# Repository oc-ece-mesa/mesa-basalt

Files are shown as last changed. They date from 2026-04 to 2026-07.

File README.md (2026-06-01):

# MESA Basalt

<div>
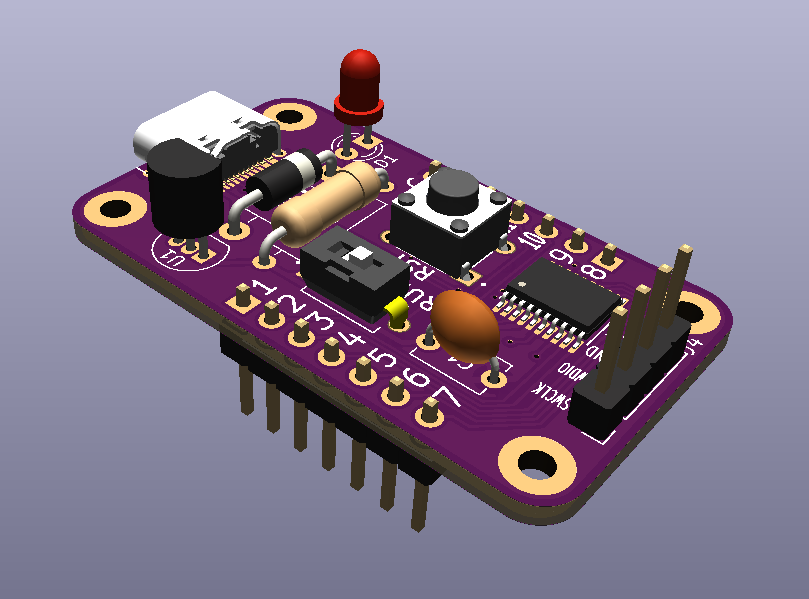
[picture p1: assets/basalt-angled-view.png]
    
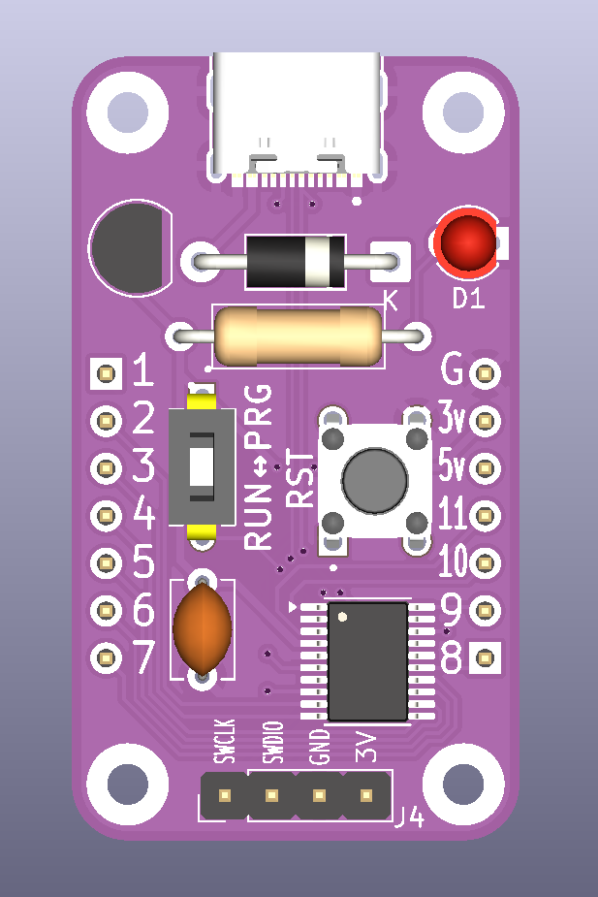
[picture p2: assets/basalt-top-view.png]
    
</div>

Basalt is a cost effective and easy to assemble (mostly through-hole components) devboard based on the STM32C071 microcontroller.

## Docs

1. [Parts List](docs/parts-list.md)
2. [Assembly & Setup](docs/assembly-and-setup.md)
3. [Dev Env Setup](docs/dev-env-setup.md)

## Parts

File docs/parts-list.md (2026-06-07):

# Basalt Parts List

<table>
    <thead>
        <tr>
            <th>QTY</th>
            <th>COST/EA</th>
            <th>DESC</th>
            <th>MFG</th>
            <th>P/N</th>
        </tr>
    </thead>
    <tbody>
        <tr>
            <td>1</td>
            <td>$2.60</td>
            <td>Basalt PCB</td>
            <td>MESA</td>
            <td>mesa-basalt-reva</td>
        </tr>
        <tr>
            <td>1</td>
            <td>$1.10</td>
            <td>Microcontroller</td>
            <td>STM</td>
            <td>STM32C071F8P6</td>
        </tr>
        <tr>
            <td>1</td>
            <td>$0.08</td>
            <td>3.3V Regulator</td>
            <td>Diotec</td>
            <td>DI78L3.3ZAB</td>
        </tr>
        <tr>
            <td>1</td>
            <td>$0.14</td>
            <td>100nF Capacitor</td>
            <td>TDK</td>
            <td>FG28X7R1H104KNT00</td>
        </tr>
        <tr>
            <td>1</td>
            <td>$0.18</td>
            <td>LED</td>
            <td>Würth Elektronik</td>
            <td>15103xxxxxxxx</td>
        </tr>
        <tr>
            <td>1</td>
            <td>$0.03</td>
            <td>2kΩ Resistor</td>
            <td>Stackpole</td>
            <td>CF12JT2K00</td>
        </tr>
        <tr>
            <td>2</td>
            <td>$0.08</td>
            <td>Pin Header</td>
            <td>Stackpole</td>
            <td>CF12JT2K00</td>
        </tr>
        <tr>
            <td>1</td>
            <td>$0.41</td>
            <td>USB Connector</td>
            <td>GCT</td>
            <td>USB4215-03-A</td>
        </tr>
        <tr>
            <td>1</td>
            <td>$0.09</td>
            <td>Pushbutton</td>
            <td>Same Sky</td>
            <td>TS02-66-50-BK-260-LCR-D</td>
        </tr>
        <tr>
            <td>1</td>
            <td>$0.46</td>
            <td>Switch</td>
            <td>Same Sky</td>
            <td>DS04-254-1L-01BK</td>
        </tr>
        <tr>
            <td>1</td>
            <td>$0.16</td>
            <td>Schottky Diode</td>
            <td>TSMC</td>
            <td>1N5817</td>
        </tr>
        <tr>
            <td>1</td>
            <td>$0.12</td>
            <td>Right Angle Pin Header</td>
            <td>Adam Tech</td>
            <td>PH1RB-04-UA </td>
        </tr>
    </tbody>
</table>

**Total Cost**: $5.45

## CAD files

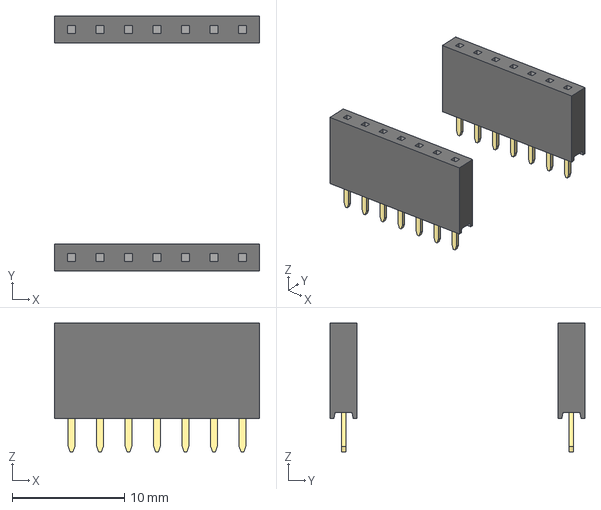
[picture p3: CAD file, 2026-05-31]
kicad-part/MESA_Basalt_RevA_Socket_Headers.step
18.3 x 22.7 x 11.5 mm

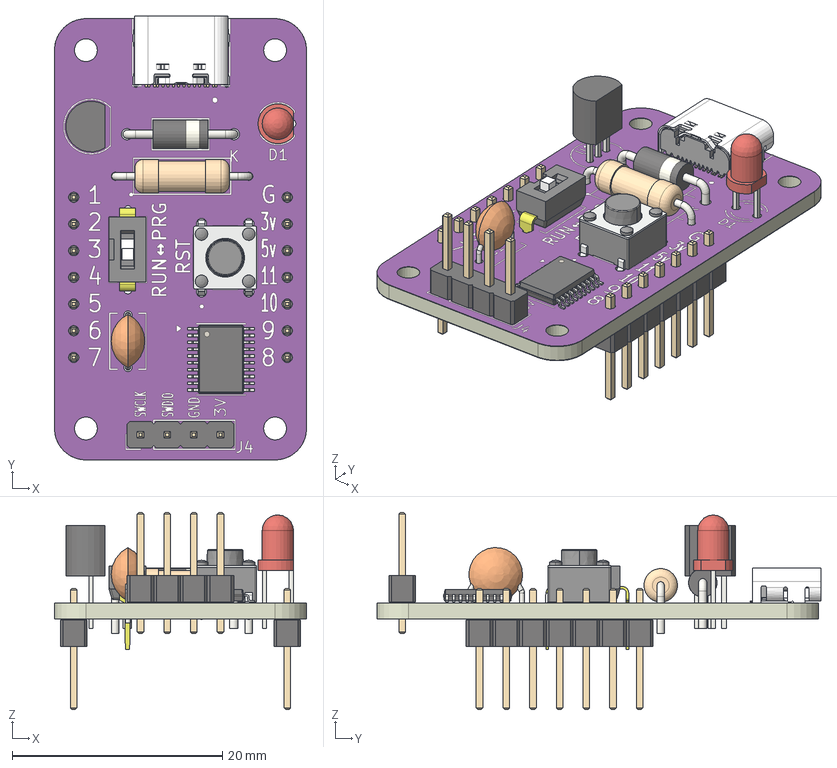
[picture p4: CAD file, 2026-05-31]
kicad-part/MESA_Basalt_RevA.step
24.0 x 42.3 x 18.8 mm
TSSOP-20_4.4x6.5mm_P0.65mm
PinHeader_1x04_P254mm_Vertical
HSG_ASM_1
TO-92_Inline_Narrow
D_DO-41_SOD81_P10.16mm_Horizontal
LED_D3.0mm
C_Disc_D51mm_W32mm_P500mm
CUI_DEVICES_DS04-254-1L-01BK
CUI_DEVICES_TS02-66-50-BK-260-SCR-D
R_Axial_DIN0309_L90mm_D32mm_P1270mm_Horizontal
PinHeader_1x07_P254mm_Vertical x 2
basalt-pcb_silkscreen x 2
basalt-pcb_soldermask x 2
basalt-pcb_PCB

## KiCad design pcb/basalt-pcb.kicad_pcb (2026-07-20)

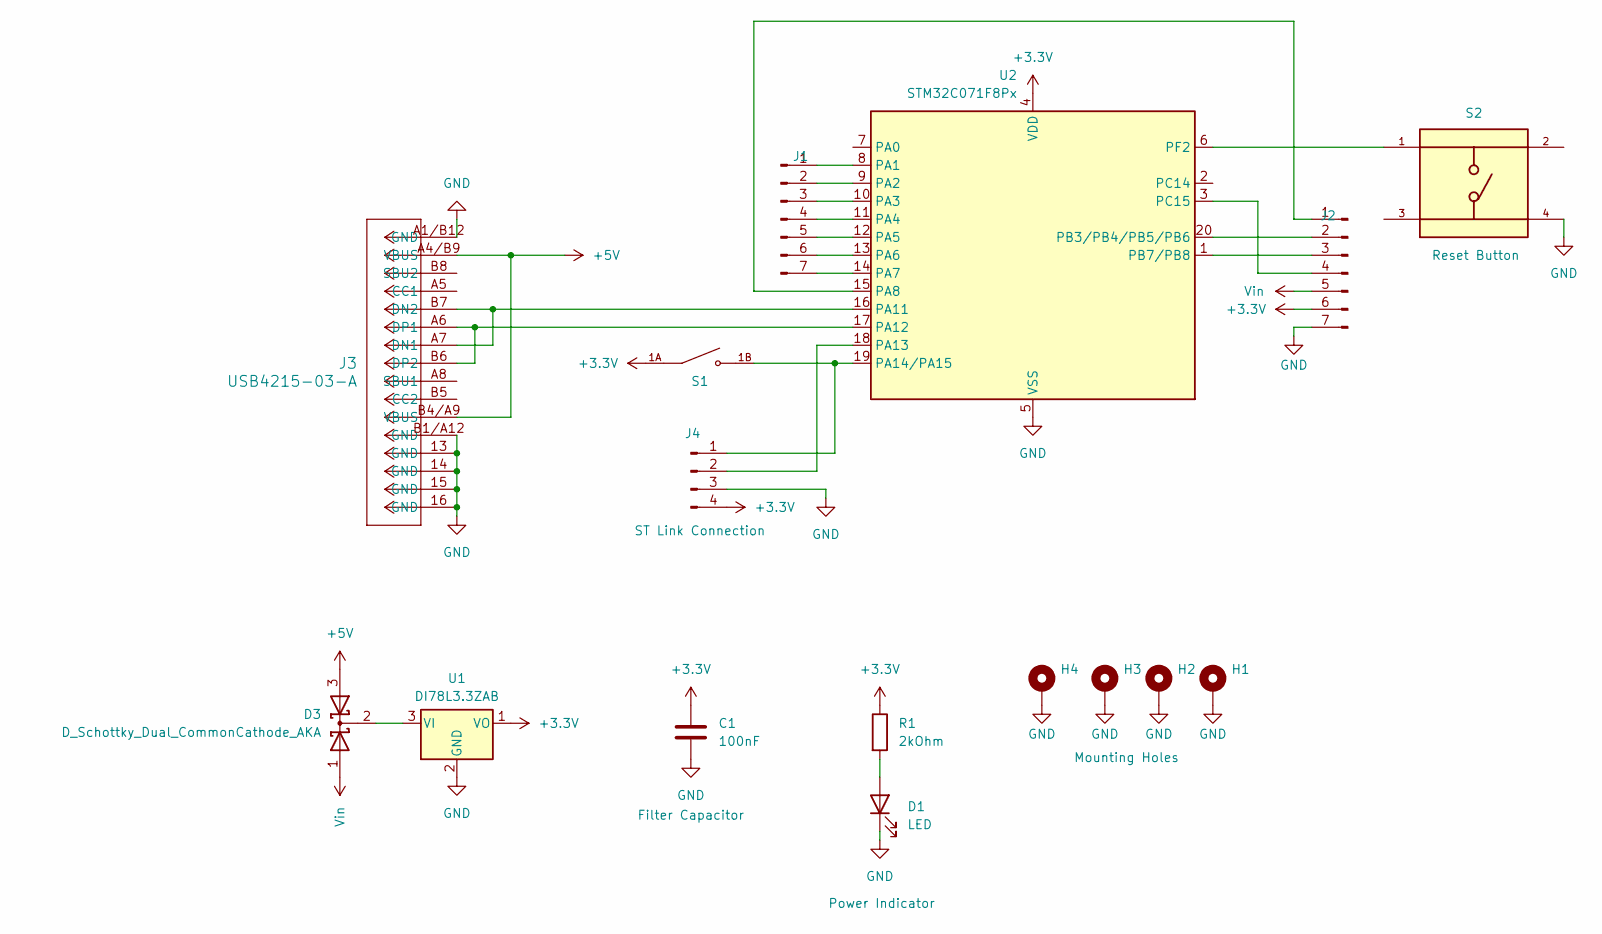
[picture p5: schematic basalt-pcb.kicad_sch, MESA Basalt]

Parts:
C1: 100nF; C_Disc_D5.1mm_W3.2mm_P5.00mm
D1: LED; LED_D3.0mm
D3: D_Schottky_Dual_CommonCathode_AKA; TO-220-3_Vertical
H1, H2, H3, H4: MountingHole_Pad; MountingHole_2.2mm_M2_Pad
J1, J2: Conn_01x07_Pin; PinHeader_1x07_P2.54mm_Vertical
J3: USB4215-03-A; CONN_8p94X6p5X3p16_12L_GCC
J4: Conn_01x04_Pin; PinHeader_1x04_P2.54mm_Vertical
R1: 2kOhm; R_Axial_DIN0309_L9.0mm_D3.2mm_P12.70mm_Horizontal
S1: DS04-254-1L-01BK; SW_DS04-254-1L-01BK; PARTREV V0.0
S2: TS02-66-50-BK-260-SCR-D; SW_TS02-66-50-BK-260-SCR-D; PARTREV 1.0
U1: DI78L3.3ZAB; TO-92_Inline
U2: STM32C071F8Px; TSSOP-20_4.4x6.5mm_P0.65mm

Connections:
+3.3V: C1.1, J2.6, J4.4, R1.1, S1.1A, U1.1 (VO), U2.4 (VDD)
+5V: D3.3 (A), J3.A4/B9 (VBUS), J3.B4/A9 (VBUS)
GND: C1.2, D1.1 (K), H1.1 (1_1), H2.1 (1_1), H3.1 (1_1), H4.1 (1_1), J2.7, J3.13 (GND), J3.14 (GND), J3.15 (GND), J3.16 (GND), J3.A1/B12 (GND), J3.B1/A12 (GND), J4.3, S2.4, U1.2 (GND), U2.5 (VSS)
unnamed: D1.2 (A), R1.2
unnamed: D3.2 (K), U1.3 (VI)
unnamed: J1.1, U2.8 (PA1)
unnamed: J1.2, U2.9 (PA2)
unnamed: J1.3, U2.10 (PA3)
unnamed: J1.4, U2.11 (PA4)
unnamed: J1.5, U2.12 (PA5)
unnamed: J1.6, U2.13 (PA6)
unnamed: J1.7, U2.14 (PA7)
unnamed: J2.1, U2.15 (PA8)
unnamed: J2.2, U2.20 (PB3/PB4/PB5/PB6)
unnamed: J2.3, U2.1 (PB7/PB8)
unnamed: J2.4, U2.3 (PC15)
unnamed: J3.A7 (DN1), J3.B7 (DN2), U2.16 (PA11)
unnamed: J3.A6 (DP1), J3.B6 (DP2), U2.17 (PA12)
unnamed: J4.1, S1.1B, U2.19 (PA14/PA15)
unnamed: J4.2, U2.18 (PA13)
unnamed: S2.1, U2.6 (PF2)
Vin: D3.1 (A), J2.5

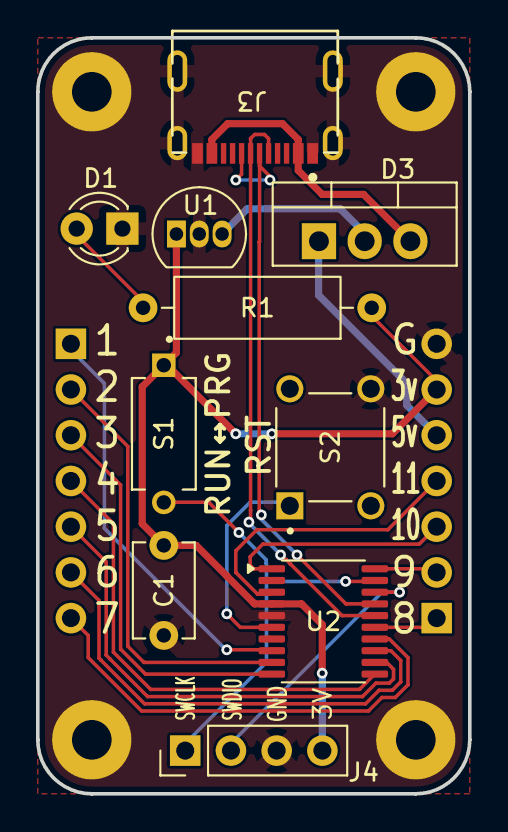
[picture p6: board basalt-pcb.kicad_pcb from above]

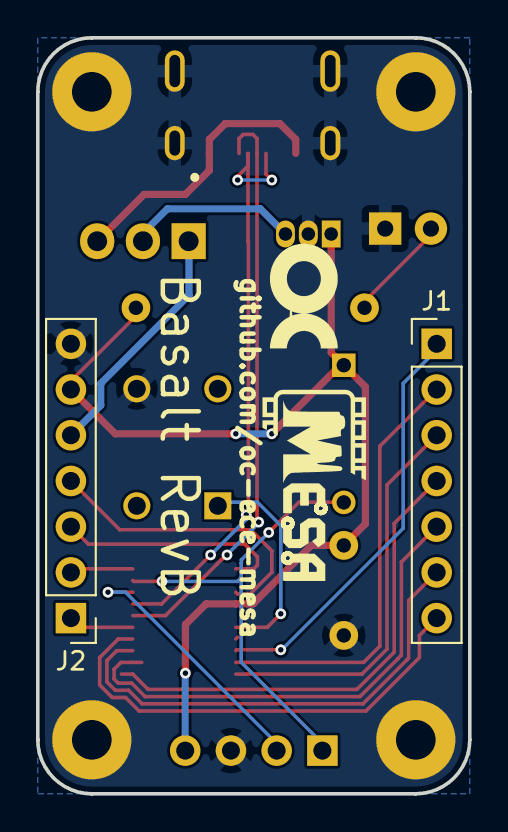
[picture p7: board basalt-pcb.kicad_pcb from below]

Board: 2 copper layers, 24.0 x 42.0 mm, 16 parts (2 on the bottom side), 22 nets.

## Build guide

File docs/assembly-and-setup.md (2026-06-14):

# **Assembly**

1. Solder the SMD parts (USB C connector, and MCU) first, using solder paste

   ***NOTE**: You can use a soldering iron, but it is tricky, make sure to use a fine tip*
   
   ***NOTE**: It is recommended to not solder all of the USB C connector case fins at this step, just lightly solder one of them, that way the connector can be removed easier if you need to resolder it after testing*
   
2. Verify there are no shorts with a multimeter (particularly check between the GND and 5V pins)
3. Solder the 3.3V regulator and diode
4. You now have the minimal required parts for the USB to work, plug the board into a computer to test if it shows up as a USB device. If it does not, you have a short or bad connection somewhere.
5. Solder all remaining components

   ***NOTE**: For the program mode switch, the side that says “ON” points towards the silkscreen text “PRG”.*
   
   ***NOTE**: For the LED, the flat side points toward the square pad.*

# **Setting Option Bits**

1. Setup your MCUs option bits to allow entering USB bootmode after initial programming
   - Plug your dev board into your computer with a USB-C cable
   - Run STM32CubeProgrammer
   - Select “USB” in the dropdown in the upper right corner

<p align="center">
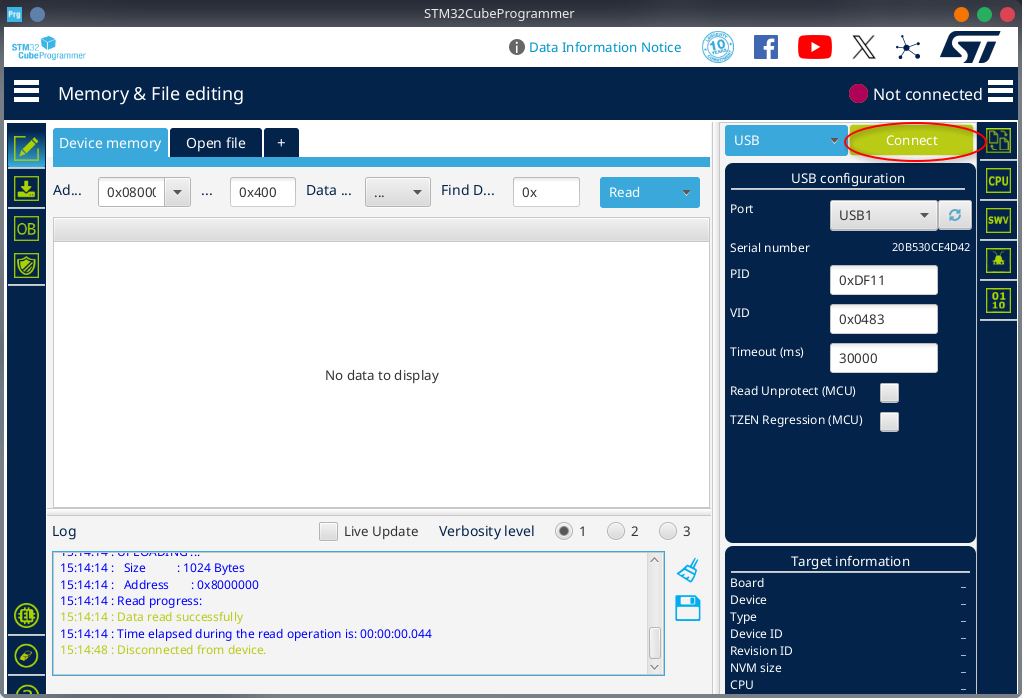
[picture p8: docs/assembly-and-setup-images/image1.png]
    
</p>

2. Click the Port refresh button, the port should auto populate as shown

<p align="center">
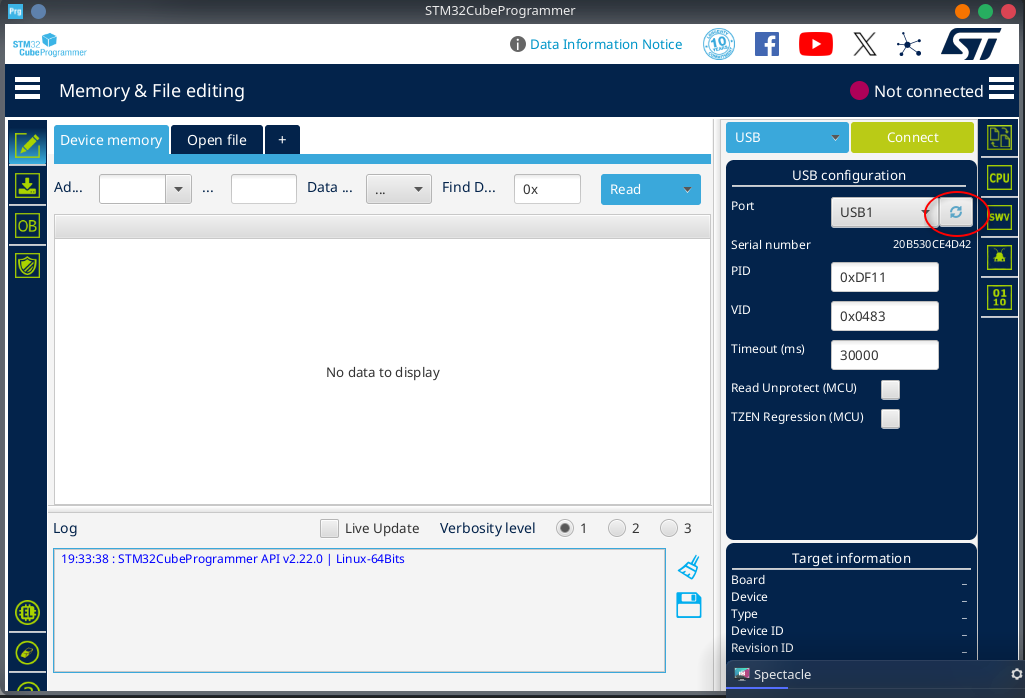
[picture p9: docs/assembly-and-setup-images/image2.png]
    
</p>

3. Click “Connect”

<p align="center">
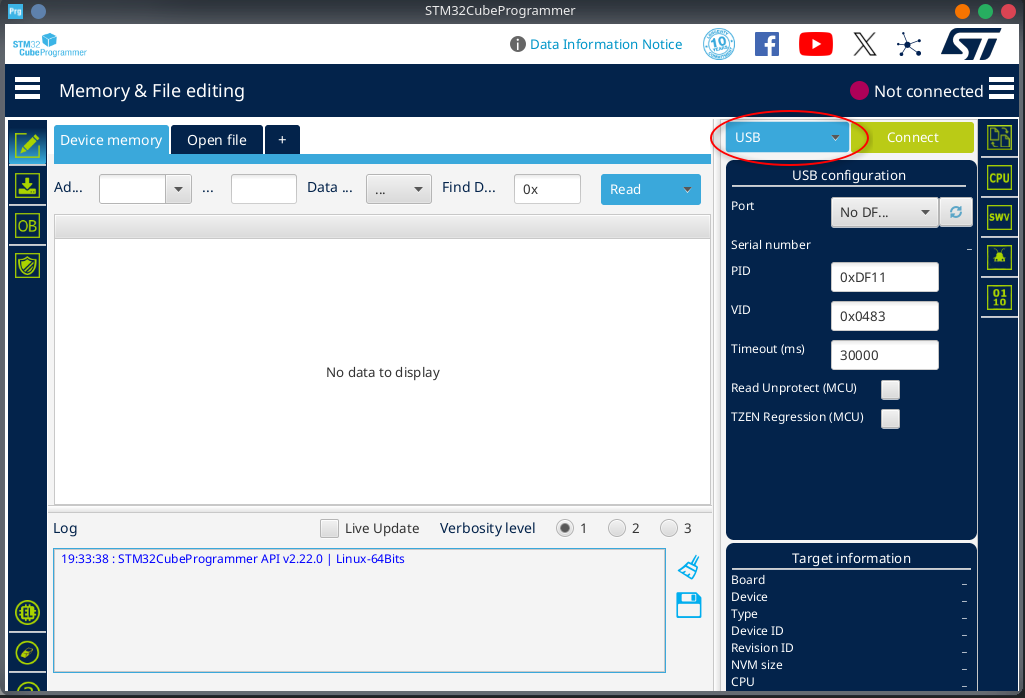
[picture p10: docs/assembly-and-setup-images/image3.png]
    
</p>

You should see the indicator turn green and say “Connected” and the section on the left should populate with binary data, as shown below.

<p align="center">
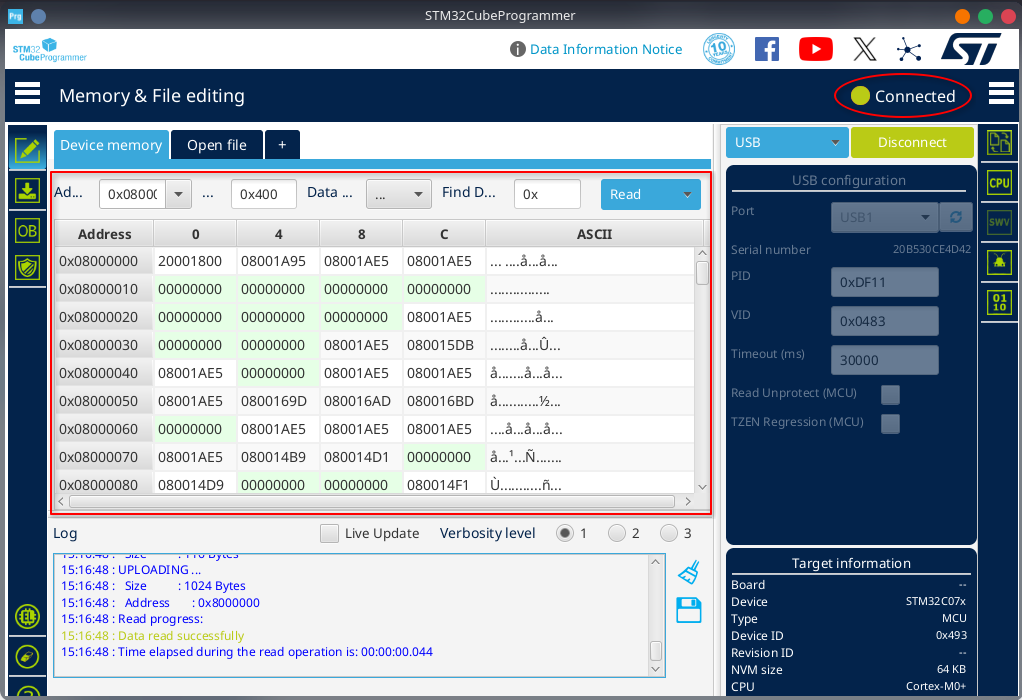
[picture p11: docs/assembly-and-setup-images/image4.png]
    
</p>

4. Click on “OB” on the left-hand toolbar and open the “User Configuration” dropdown

<p align="center">
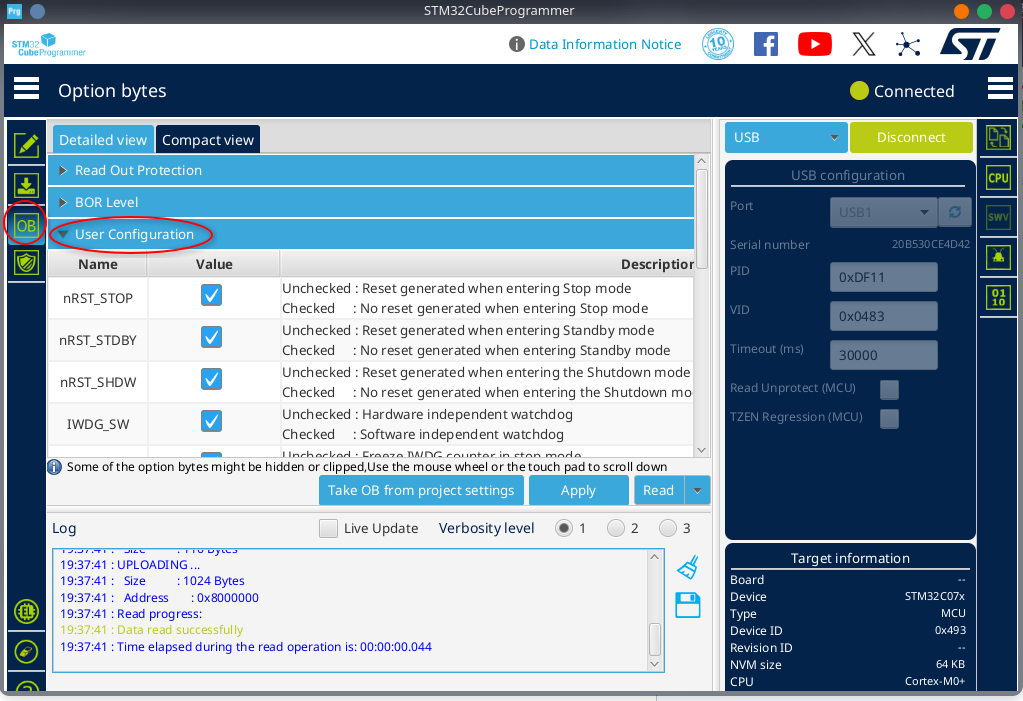
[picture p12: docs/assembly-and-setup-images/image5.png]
    
</p>

5. Scroll down to “nBOOT\_SEL” and uncheck it; then click “Apply”.

<p align="center">
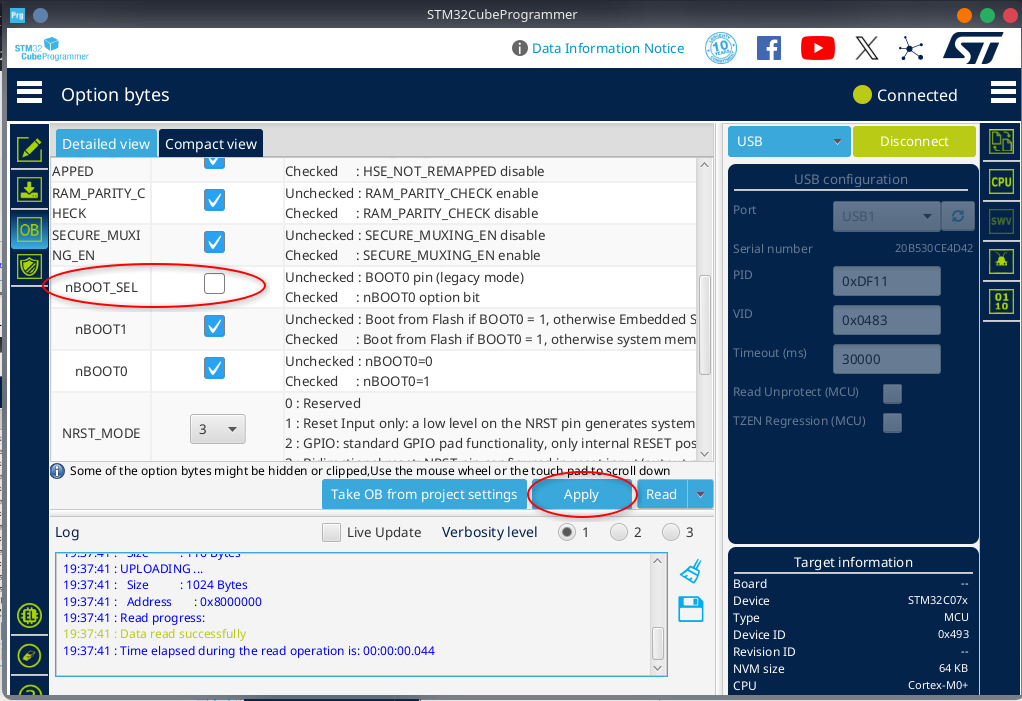
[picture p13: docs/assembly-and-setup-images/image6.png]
    
</p>

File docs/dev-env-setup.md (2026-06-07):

# Basalt Dev Env Setup

## Setup Development Environment

1. Install Arduino IDE

	**Note**: *Arduino IDE may be in your app store / software center, check there first. Otherwise, follow the steps below*

   - Go to Arduino’s software page [here](https://www.arduino.cc/en/software/)
   - Scroll down to the Arduino IDE box
   - Select your OS from the dropdown and click “DOWNLOAD”

<p align="center">
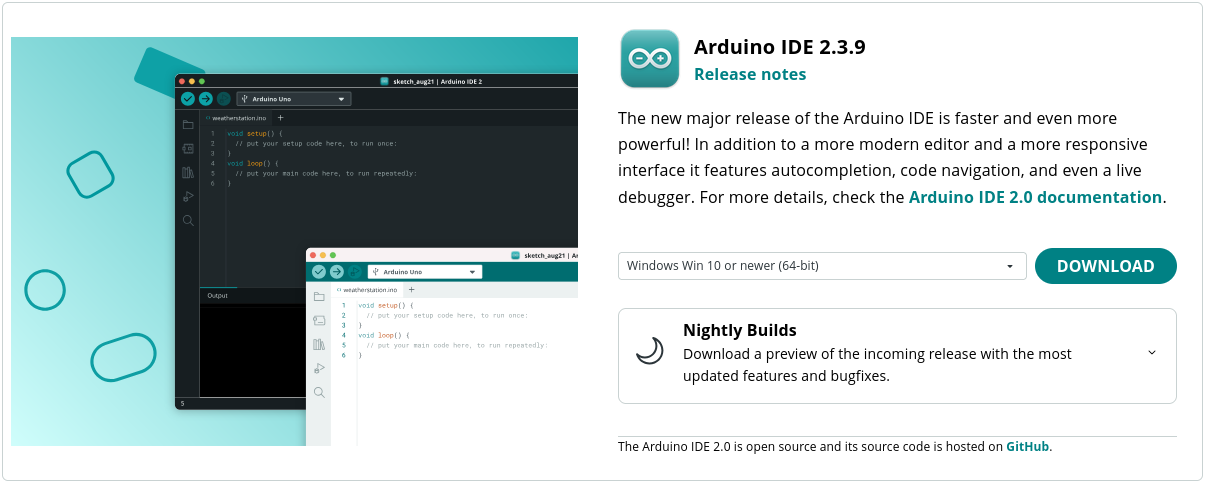
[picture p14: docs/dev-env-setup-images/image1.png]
    
</p>

2. Run the installer
3. Add support for STM32 boards
   - In Arduino IDE, under File / Preferences, add `https://github.com/stm32duino/BoardManagerFiles/raw/main/package\_stmicroelectronics\_index.json` to “Additional boards manager URLs”

<p align="center">
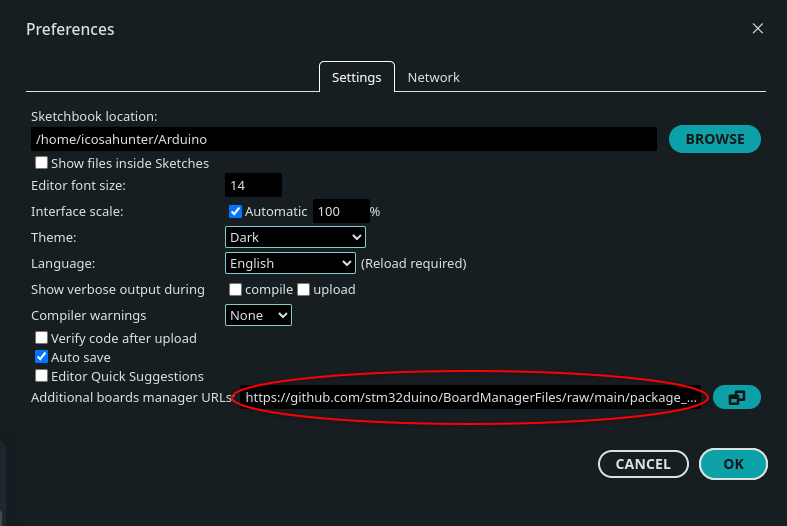
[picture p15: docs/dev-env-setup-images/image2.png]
    
</p>

2. Under Tools / Board / Boards Manager… search for and install “STM32 MCU based boards”

<p align="center">
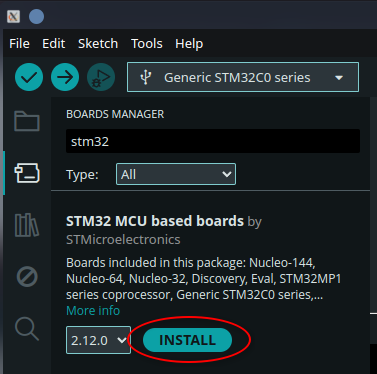
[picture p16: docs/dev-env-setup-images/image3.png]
    
</p>

3. Install STM32CubeProgrammer
   - Download the appropriate installer for your OS from [here](https://www.st.com/en/development-tools/stm32cubeprog.html#st-get-software)  
   - Follow the install instructions for your OS from the software manual [here](https://www.st.com/resource/en/user_manual/um2237-stm32cubeprogrammer-software-description-stmicroelectronics.pdf)

## Setup a New Arduino Sketch

1. Run Arduino IDE
2. Under File click “New Sketch”
3. Hover over the dropdown next to the run button and click “Select other board and port…”

<p align="center">
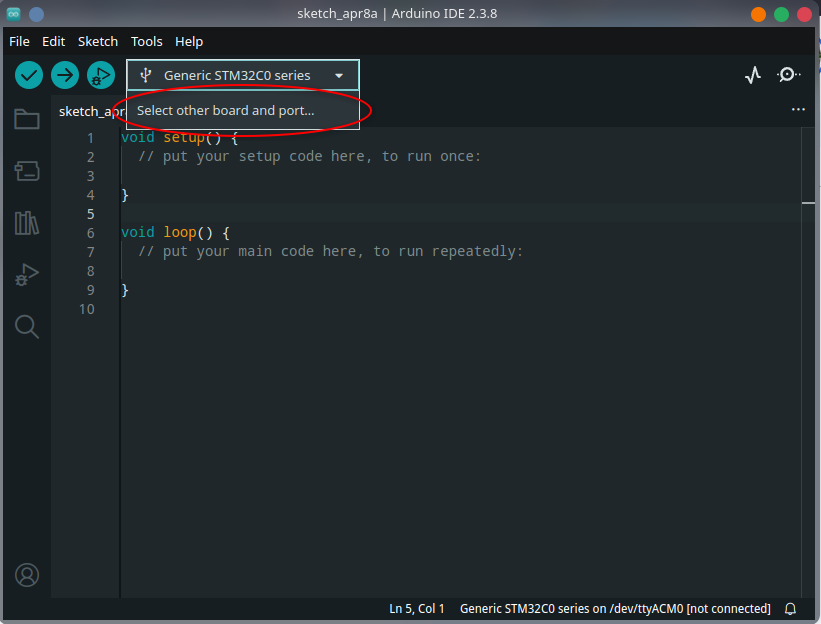
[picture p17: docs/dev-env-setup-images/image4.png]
    
</p>

4. In the pop-up search for and select “Generic STM32C0 series” and then click “OK”.

<p align="center">
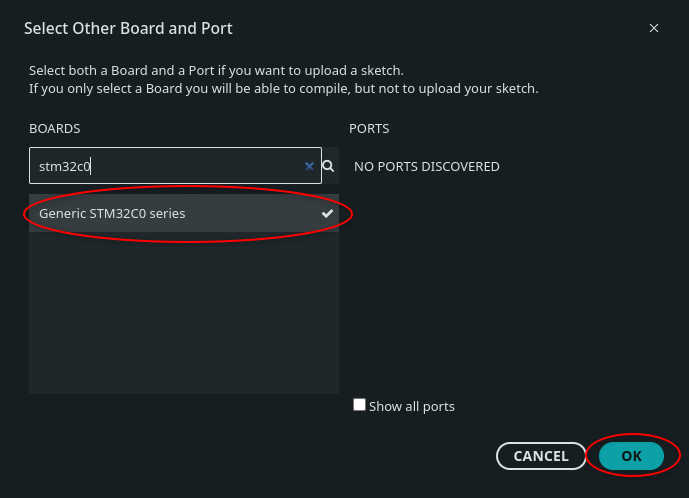
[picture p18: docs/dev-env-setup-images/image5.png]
    
</p>

5. Under Tools / Board part number: Select “Generic C071G8Ux”

<p align="center">
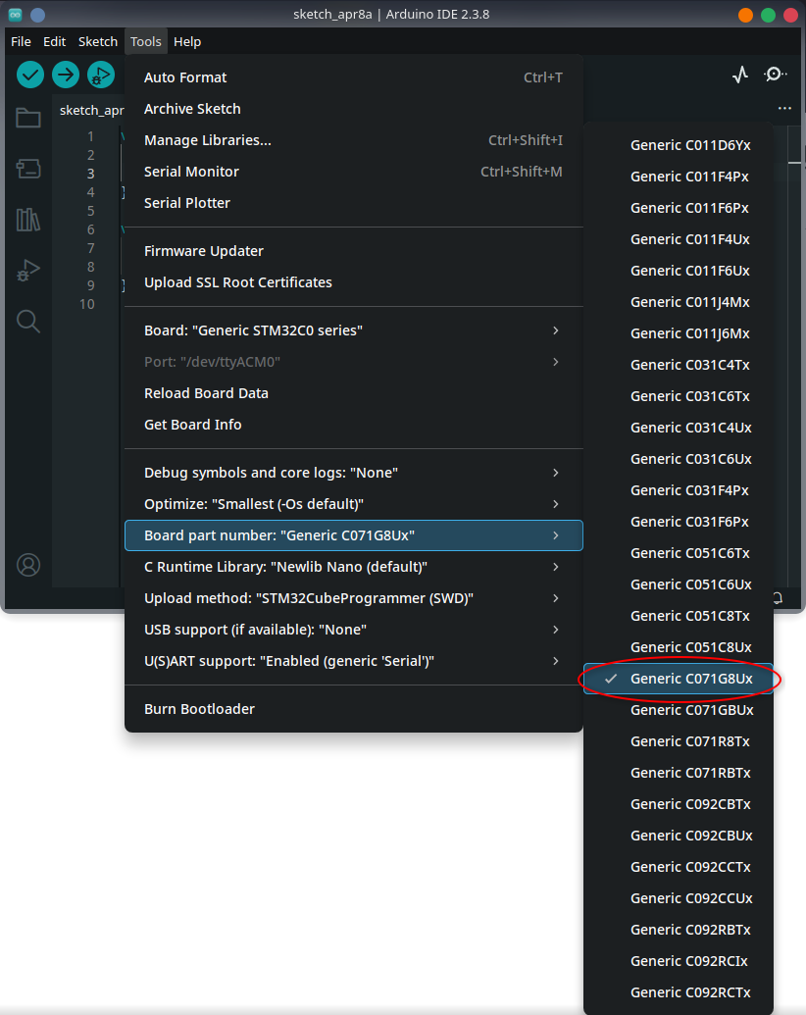
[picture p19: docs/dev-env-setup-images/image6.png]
    
</p>

6. Under Tools / Upload method: Select “STM32CubeProgrammer (DFU)”

<p align="center">
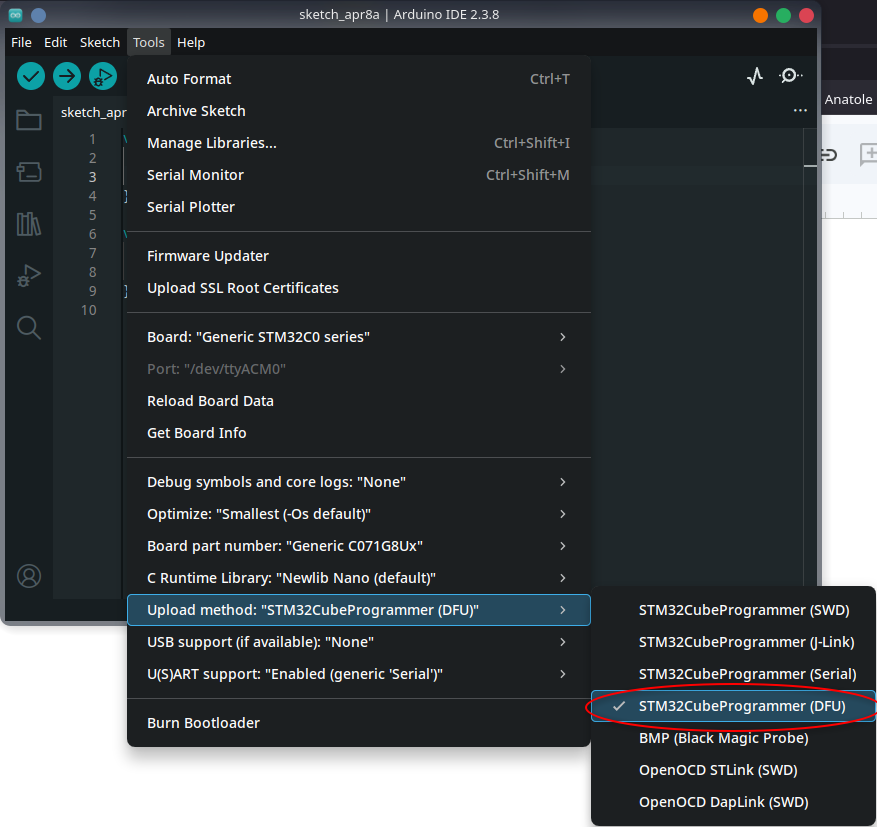
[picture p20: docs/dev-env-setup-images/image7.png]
    
</p>

7. Save your sketch with Ctrl \+ S

## Upload a Sketch to the Board

1. Open the sketch in Arduino IDE
2. Plug your breadboard into your computer with a USB-C cable
3. Set “PRG SW” to closed position and click “RST BTN” on your breadboard

	**Note**: *If PRG SW is closed, the board will boot into USB DFU mode on a reboot/reset, otherwise it will boot into your program, if there is one.*

4. Your computer should get a notification that a USB device named “STMicroelectronics DFU in FS Mode” has been connected.  
5. Click the “Start Debugging” button. After the upload is complete you should see a success message in the output box and get a notification that the USB device has disconnected.

<p align="center">
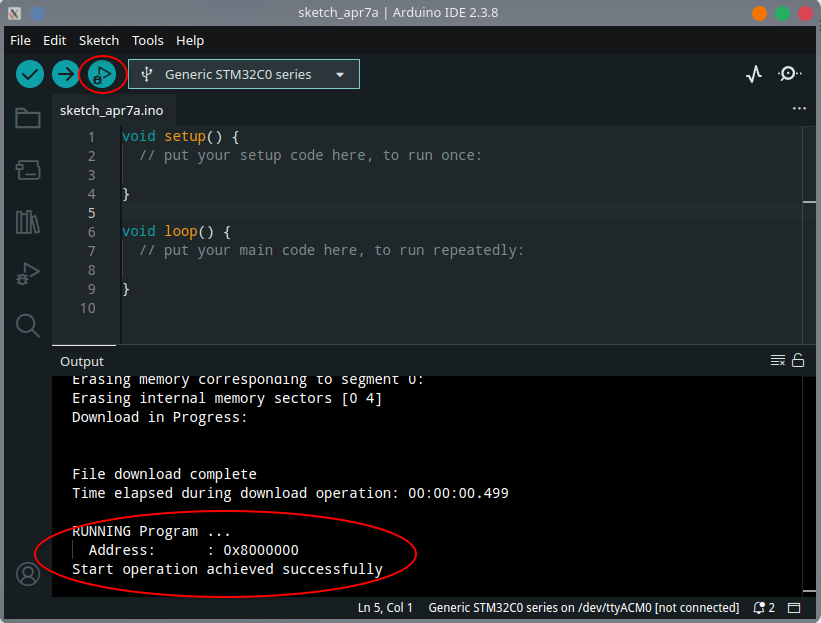
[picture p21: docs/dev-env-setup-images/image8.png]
    
</p>

6. Set “PRG SW” to open position

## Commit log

2026-04-23 Add pcb and footprint
    [basalt-pcb.kicad_pcb, basalt-pcb.kicad_sch]
2026-04-24 Expose more pins, add ST-link pins at back, add diode to prevent backfeeding USB port
    [basalt-pcb.kicad_pcb, basalt-pcb.kicad_sch]
2026-04-24 Label additions and tweaks to pcb. Update sym/footprint.
    [basalt-pcb.kicad_pcb]
2026-04-30 Update with new pin count (removing pins that cannot be accessed with existing arduino ide variant), start work on arduino board config
    [basalt-pcb.kicad_pcb, basalt-pcb.kicad_sch]
2026-04-30 Add 3D models and 3D model images to README
    [basalt-pcb.kicad_pcb]
2026-05-02 Switch to using STM32C071G8U6 that is supported by STM32duino currently
    [basalt-pcb.kicad_pcb, basalt-pcb.kicad_sch]
2026-05-02 Undo accidental merge...
    [basalt-pcb.kicad_pcb, basalt-pcb.kicad_sch]
2026-05-02 Increase power trace widths
    [basalt-pcb.kicad_pcb]
2026-05-02 Small tweaks to PCB, add logo, etc.
    [basalt-pcb.kicad_pcb]
2026-05-02 Minor updates to pcb, update gitignore
    [basalt-pcb.kicad_pcb, basalt-pcb.kicad_sch]
2026-05-02 Minor edits to pcb and titleblocks
    [basalt-pcb.kicad_pcb, basalt-pcb.kicad_sch]
2026-05-03 Fix mounting holes
    [basalt-pcb.kicad_pcb, basalt-pcb.kicad_sch]
2026-05-04 Update kicad part footprint
2026-05-04 Update 3d images
    [basalt-pcb.kicad_pcb]
2026-05-04 Add STEP file to kicad part folder
    [MESA_Basalt.step]
2026-05-15 Update, rev2, fix silkscreen and make board narrower
    [basalt-pcb.kicad_pcb]
2026-05-15 Fix titleblocks (should be rev A)
    [basalt-pcb.kicad_pcb, basalt-pcb.kicad_sch]
2026-05-31 Update kicad parts, add model for socket headers
    [MESA_Basalt.step, MESA_Basalt_RevA.step, MESA_Basalt_RevA_Socket_Headers.step]
2026-05-31 Remove WIP arduino board variant folder
2026-06-07 Add assembly and setup doc
2026-06-07 Update assembly doc
2026-07-20 Begin work on Rev B with diode array / dedicated Vin pin
    [basalt-pcb.kicad_pcb, basalt-pcb.kicad_sch]
